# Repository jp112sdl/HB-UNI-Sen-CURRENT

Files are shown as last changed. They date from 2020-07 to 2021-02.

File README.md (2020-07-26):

# HB-UNI-Sen-CURRENT

## Universeller Stromsensor für HomeMatic
unterstützt 
 - YHDC SCT013-015; -020; -030; -050; -100 / 1V Sensoren
 - INA219 _(work in progress)_
 - ACS712 _(work in progress)_
 
 ## Beispielprojekt: 3-Phasen Strommessung im Verteilerschrank
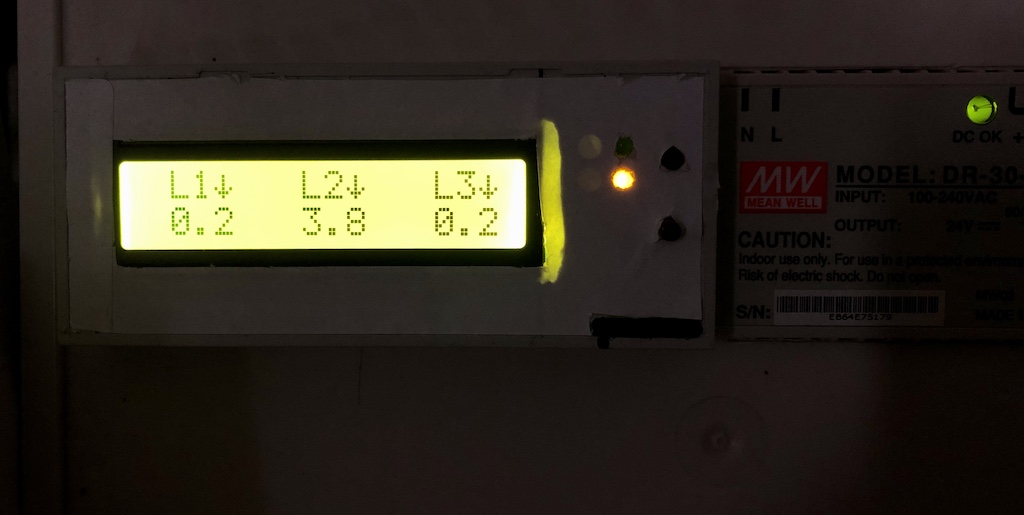
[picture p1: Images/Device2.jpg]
Dev2
 
 
 ## Bauteile
  - 1x Arduino Pro Mini (**8 MHz, 3.3V**) [AliExpress](https://de.aliexpress.com/item/32342672626.html)
  - 1x CC1101 868MHz Funkmodul [AliExpress](https://de.aliexpress.com/item/32924239954.html)
  - 2x ADS1115 16bit ADC [AliExpress](https://de.aliexpress.com/item/32954034047.html)
  - 3x SCT013-030/1V Stromsensor [AliExpress](https://de.aliexpress.com/item/4000189334448.html)
  - 1x 16x2 LCD Display [AliExpress](https://de.aliexpress.com/item/32685612494.html)
  - 2x Taster
  - 2x LED
  - 2x Widerstand 330 Ohm
  - ext. Stromversorgung 5V
 
 ## Schaltungsübersicht
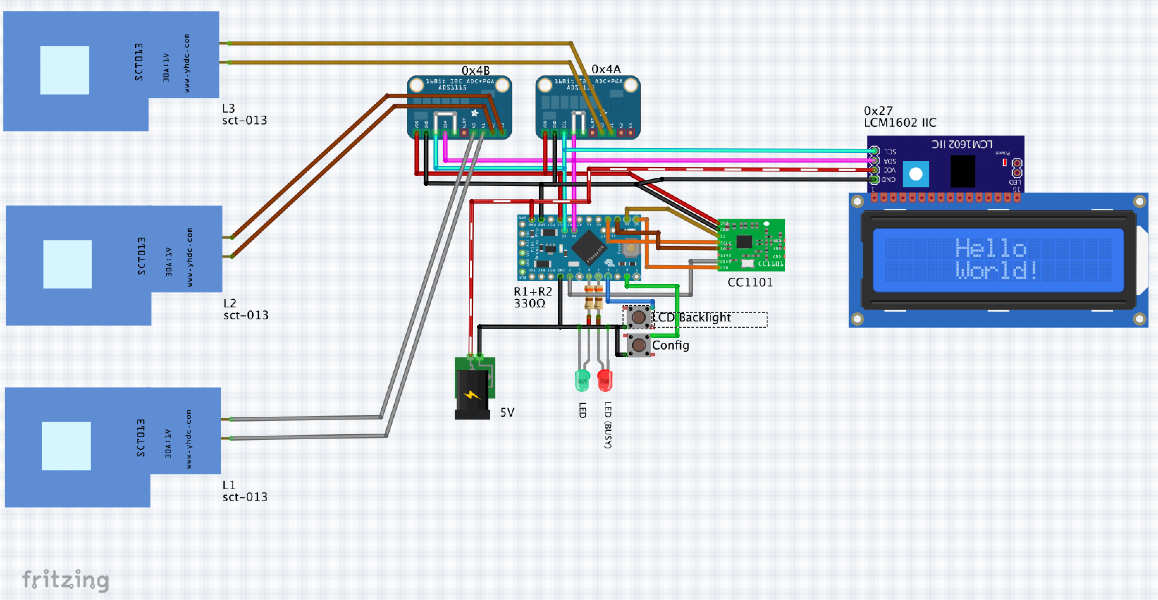
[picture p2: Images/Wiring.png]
Wiring
 
 
 ## CCU Einstellungen
 **Geräteeinstellungen**
 - Spannungsversorgung
   - Netzbetrieb
   - Batteriebetrieb (es erscheint dann zusätzlich ein Feld für die Low-Battery Einstellung)
 - Messintervall
 - Sendeintervall
   - Es wird der Mittelwert über die eingestellte Anzahl Messungen gebildet und übertragen. Der zeitliche Sendeabstand beträgt (Messintervall x Sendeintervall) Sekunden
 - Displayhinterleuchtungszeit
   - Dauer der LCD Hintergrundbeleuchtung nach Druck auf Taster 2 (0 = Dauerhaft EIN)
 - Prüfung auf Grenzwerte
   - bei jeder Messung: wird bei einer einzelnen Messung ein Grenzwert über-/unterschritten, wird sofort der Entscheidungswert gesendet
   - Mittelwert: liegt der Mittelwert (s.o.) über/unter einem Grenzwert, wird der Entscheidungswert erst im Sendeintervall gesendet
 
 **Kanaleinstellungen**
  - Sensortyp: Auswahl des verwendeten Sensortyps
  - Messdauer: Dauer der Messung (Mittelwert über n Millisekunden)
  - Oberer / Unterer Grenzwert und Entscheidungswert: hierüber lassen sich direkt verknüpfte Aktoren bei über-/unterschreiten von Grenzwerten schalten

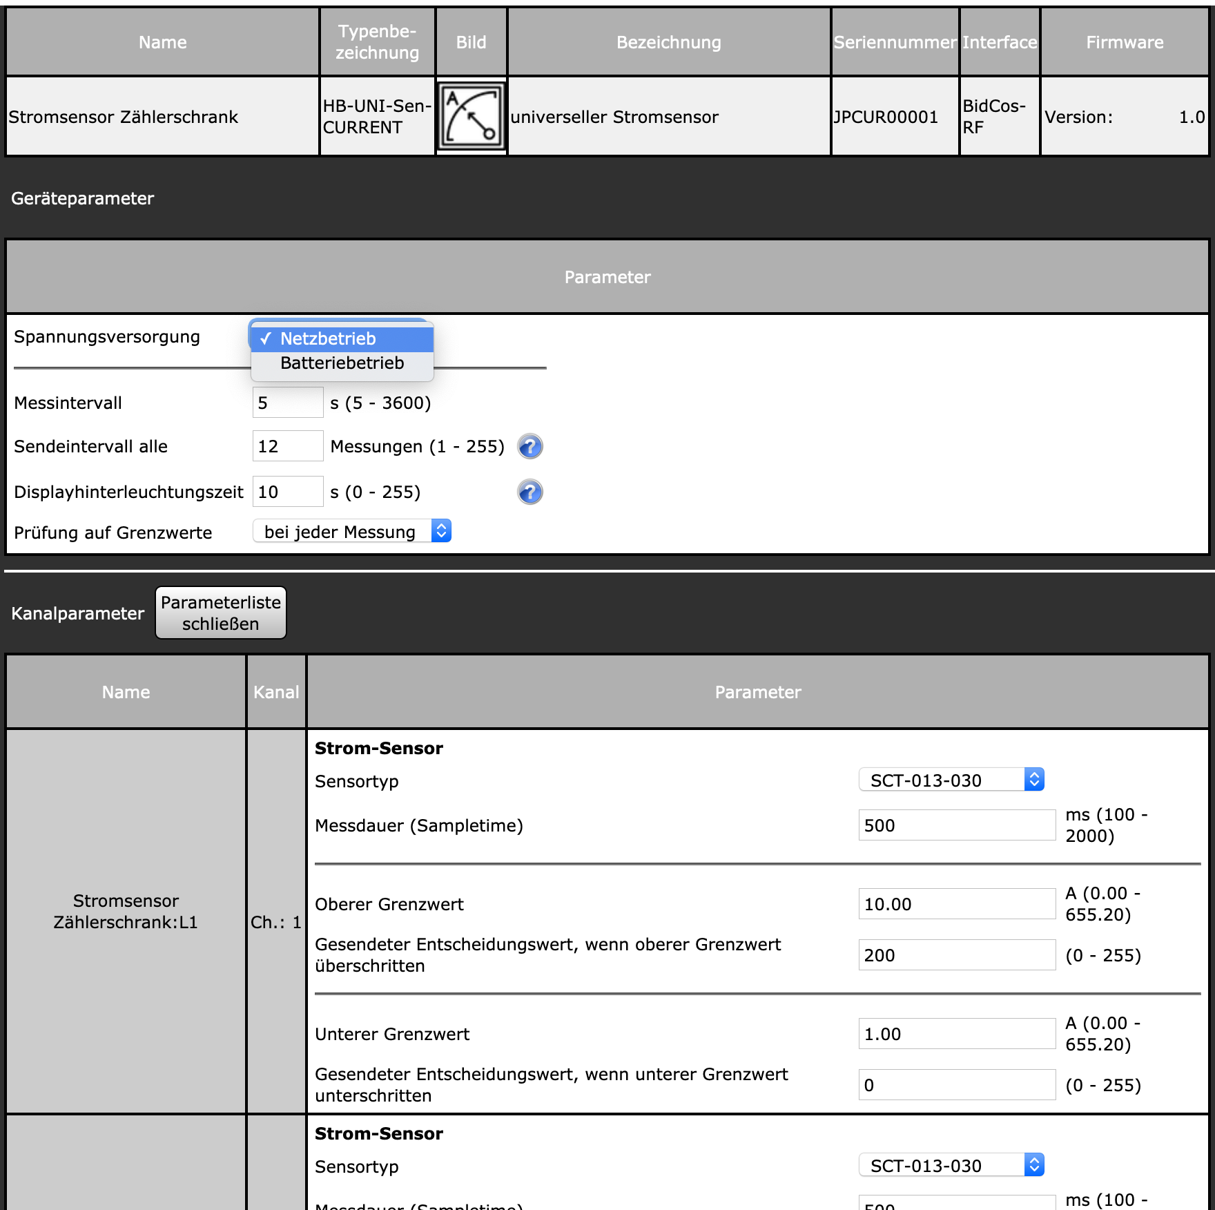
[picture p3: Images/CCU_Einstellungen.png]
Einstellungen
 

 ## CCU Bedienung
 Anzeige von aktueller Stromstärke, ggf. zuletzt gesendetem Entscheidungswert sowie Fehler (bei Ausfall eines ADS1115 Moduls)
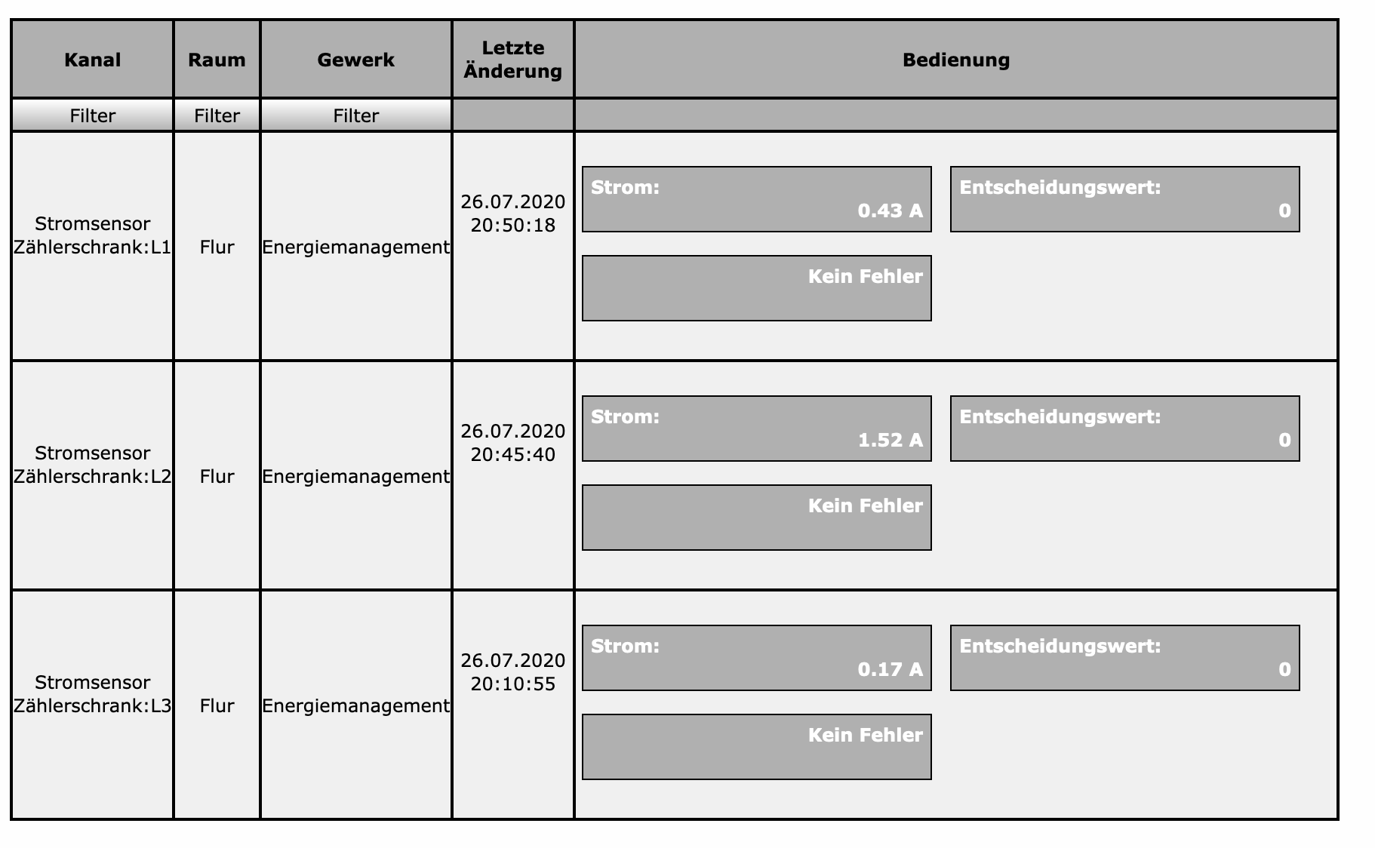
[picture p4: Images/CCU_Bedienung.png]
Bedienung


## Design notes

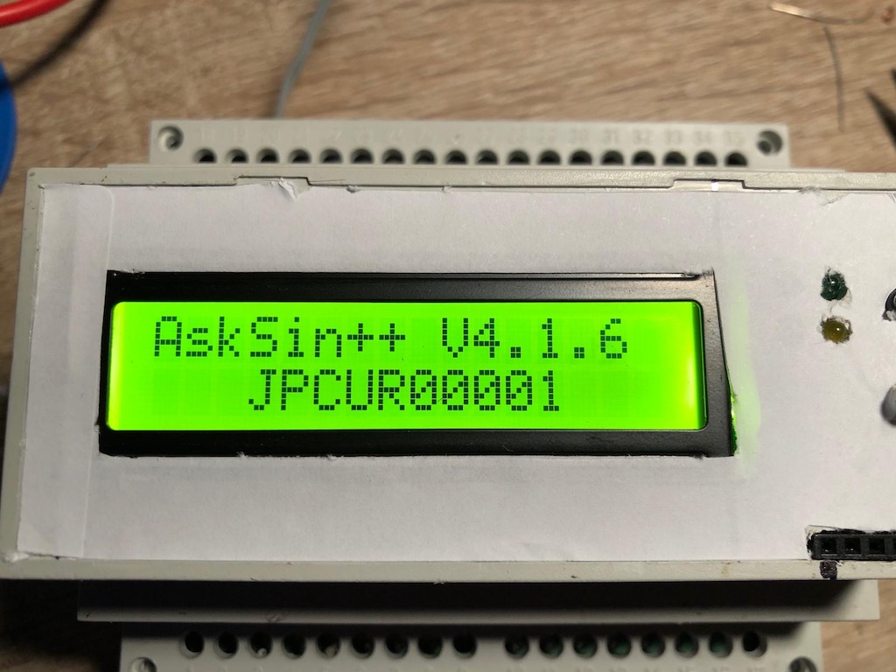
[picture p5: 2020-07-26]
Images/Device1.jpg

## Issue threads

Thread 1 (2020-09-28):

Frage zum Start

Michel83, 2020-09-28:
Hi, ich habe ein kleine Frage zum Start des Sensors.

Ist es normal das wenn ich Spannung auf den Sensor gebe die grüne LED Blinkt dann die Rote Leuchtet und im Terminal dies steht

`AskSin++ V4.1.2 (Sep 28 2020 19:35:40)
Address Space: 32 - 156
CC init1
CC Version: 14
 - ready
Config Freq: 0x2165E2
ADS1115 init at address 4B OK, gain 1024
ADS1115 init at address 4A OK, gain 1024
iVcc: 3332
`

Danach passiert erst mal eine ganze zeit nichts mehr im Display habe ich die Anzeige :

AskSinn++ V4.1.2
JPCUR00001

ich denke das ist alles so normal, das Problem was ich habe das nach einer zeit dann im Display L1 mit 0.0, L2 mit 214748, und L3 mit 0.0 steht wo muss ich suchen ?

Ich habe 50A Wandler direkt auf die ADS gelötet

Grüße
und Super Arbeit !

Michel83, 2020-09-28:
Kurzes update ich habe ihn mal angelernt, hier zeigt er auf L2 keine Werte allerdings bekomme ich die Servicemeldung mit daten stehen zur Übertragung an nicht weg
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

jp112sdl, 2020-09-28:
> allerdings bekomme ich die Servicemeldung mit daten stehen zur Übertragung an nicht weg

Configtaster mal kurz gedrückt?

> das Problem was ich habe das nach einer zeit dann im Display L1 mit 0.0, L2 mit 214748, und L3 mit 0.0 steht wo muss ich suchen ?

Hmm, bin ich auch grad überfragt. Der Wert wird ja per I2C direkt vom ADS1115 ausgelesen

Michel83, 2020-09-28:
Danke für die schnelle Antwort, was mir noch aufgefallen ist im Display fehlt bei L2 auch der Pfeil nach unten, die config Taste hatte ich kurz gedrückt wie die rote LED aus war. Danach blinkte die grüne zweimal kurz aber die Meldung in der ccu war nicht weg.

Ich versuche morgen nochmal ein anderen ProMini, da ich diesen auch seltsamer weise nur mit dem diamex Programmer beschreiben konnte also nicht mit dem ftdi

Michel83, 2020-09-29:
Hi,

ich habe nochmal getestet den ProMini habe ich noch nicht gewechselt aber mal die Adressen der ADS1115 gewechselt gleiches Phänomen L2 nur mist und kein Pfeil, danach habe ich dem ADS1115 4B die Adresse geklaut siehe :
`Address Space: 32 - 156
CC init1
CC Version: 14
 - ready
Config Freq: 0x2165E2
ADS1115 init at address 4B FAILED!
ADS1115 init at address 4A OK, gain 1024
iVcc: 3322
measure() #1 of 12
sendConditionalSwitchCommand
<- 0C 01 A2 41 F34E01 35C9DA 01 00 00  - 66891
-> 0C 50 86 70 025F31 000000 00 A7 3B  - 66895
waitAck: 00
<- 0C 01 A2 41 F34E01 35C9DA 01 00 00  - 67532
waitAck: 00
<- 0C 01 A2 41 F34E01 35C9DA 01 00 00  - 68167
waitAck: 00
<- 0C 01 A2 41 F34E01 35C9DA 01 00 00  - 68802
waitAck: 00
<- 0C 01 A2 41 F34E01 35C9DA 01 00 00  - 69439
waitAck: 00
<- 0C 01 A2 41 F34E01 35C9DA 01 00 00  - 70074
waitAck: 00
sendConditionalSwitchCommand
<- 0C 02 B2 41 F34E01 FFFFFF 03 01 FF  - 71071
waitAck: 00
<- 0C 02 B2 41 F34E01 FFFFFF 03 01 FF  - 72060
waitAck: 00
<- 0C 02 B2 41 F34E01 FFFFFF 03 01 FF  - 73050
waitAck: 00
<- 0C 02 B2 41 F34E01 FFFFFF 03 01 FF  - 74039
waitAck: 00
<- 0C 02 B2 41 F34E01 FFFFFF 03 01 FF  - 75028
waitAck: 00
<- 0C 02 B2 41 F34E01 FFFFFF 03 01 FF  - 76015
waitAck: 00
ignore 10 FF 86 53 4D0E4E 000000 00 00 8F 8E 00 02 25  - 76664
`

jetzt ist L2 auf Null allerdings fehlt nun auch bei L3 der Pfeil.

jp112sdl, 2020-09-29:
Also an den Pfeilen solltest du dich erstmal nicht orientieren.
Sie zeigen lediglich an, ob ein Grenzwert über-/unterschritten wurde.

Komisch ist auch die Zieladresse FFFFFF
```
sendConditionalSwitchCommand
<- 0C 02 B2 41 F34E01 FFFFFF 03 01 FF  - 71071
```

Du solltest noch mal einen kompletten Reset machen (Ablernen mit Werkseinstellung), um das EEPROM neu zu intialisieren.
Dann noch mal neu anlernen.

Vielleicht sind auch dann die L2 Probleme weg

Michel83, 2020-10-03:
Hi, sorry hatte heute erst Zeit zum probieren.

Er läuft, Ablernen mit Werkseinstellung war des Rätsels Lösung das L2 Problem war danach auch weg.

Jetzt habe ich zwar noch das Schönheitsproblem das bei Geräte nicht der Strom sondern der lange string steht aber damit kann ich leben.

Super Arbeit und danke nochmal für den Support.

Grüsse

jp112sdl, 2020-10-03:
> Jetzt habe ich zwar noch das Schönheitsproblem das bei Geräte nicht der Strom sondern der lange string steht

Welche CCU FW Version setzt du ein?
Bei RaspberryMatic wird das (noch?) automatisch übersetzt.
Dort gibt es in der `/www/webui/webui.js` (noch?) den Eintrag
`elvST['ENERGIE_METER_TRANSMITTER|CURRENT'] = '${stringTablePowerMeterCurrent}';`

Wie ich sehe, existiert der Eintrag in der aktuellen OCCU master aber nicht mehr. :(
Bis Version 3.51 war die Übersetzung noch drin. Grrrrr...
Immer wieder Überraschungen aufs Neue... Ich werde die Übersetzung dann in der nächsten Addon Version selbst implementieren.

jp112sdl, 2020-10-03:
Ahja, man hat `stringTablePowerMeterCurrent` in `stringTableCurrent` umbenannt.

Heißt für mich: Keinerlei vorgefertigte Übersetzungen mehr nutzen.

Closed 2020-10-03.

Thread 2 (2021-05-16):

INA219 (work in progress)

elmarfaber, 2021-05-16:
Hallo,

ich habe gerade ein Projekt wo ich die Anbindung des o.g. Sensors verwenden könnte.
Ist denn die Einbindung des INA219 noch geplant?

Viele Grüße

Elmar

jp112sdl, 2021-05-16:
Hallo Elmar,

zeitlich ist meinerseits nicht absehbar, wann und ob ich das noch einbaue.

Evtl. bekommst du es selbst hin?
Beim HB-ES-PMSw1-USB habe ich den INA219 eingebaut:
https://github.com/jp112sdl/HB-ES-PMSw1-USB/blob/master/HB-ES-PMSw1-USB.ino

elmarfaber, 2021-05-17:
Hallo Jérôme,

ich bin zwar nicht so ganz unerfahren im programmieren aber ich glaube nicht,
dass ich das hinbekomme ohne mehr über die Grundstruktur von AskSin++ zu
wissen - ist schon sehr komplex. Aber ich versuche mich mal daran...

jp112sdl, 2021-05-17:
Ich hab das mal grob in den Sketch gepackt.
https://github.com/jp112sdl/HB-UNI-Sen-CURRENT/blob/dev/ina219/HB-UNI-Sen-CURRENT.ino

Die Änderungen sind überschaubar:
https://github.com/jp112sdl/HB-UNI-Sen-CURRENT/compare/dev/ina219

NUM_CHANNELS solltest du noch auf 1 setzen
https://github.com/jp112sdl/HB-UNI-Sen-CURRENT/blob/2ed1deb66944ee0305fe46d08b8e331339dcb3b2/HB-UNI-Sen-CURRENT.ino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

elmarfaber, 2021-05-17:
Okay, das ist wirklich nicht wild, hab den Sketch nun angepasst und muss jetzt nur noch die Hardware zusammenbauen
und es testen. Habe den INA226 mal mit dazu gepackt und die xml Datei um den Parameter erweitert:
...
<paramset type="MASTER" id="HB-UNI-Sen-CURRENT_ch_master">
        <parameter id="SENSOR_TYPE">
          <logical type="option">
           <option id="SCT-013-015" />
           <option id="SCT-013-020" />
           <option id="SCT-013-030" default="true" />
           <option id="SCT-013-050" />
           <option id="SCT-013-100" />
           <option id="INA219" />
		   <option id="INA226" />
           <option id="ACS712 or other" />
          </logical>
          <physical type="integer" interface="config" list="1" index="3" size="1"/>
        </parameter>
...
Ich hoffe, ich habe alles richtig gemacht. Ich melde mich, wenn ich es getestet habe...
Vielen Dank für deine Hilfe!!!!

jp112sdl, 2021-05-17:
>die xml Datei um den Parameter erweitert

Hi,

das reicht nicht.
Die WebUI Config Page hat die Liste auch noch hier:
https://github.com/jp112sdl/JP-HB-Devices-addon/blob/master/src/addon/www/config/easymodes/HB-UNI-Sen-CURRENT_ch_master.tcl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

elmarfaber, 2021-05-21:
Hallo,

also kompilieren und aufspielen ist kein Problem, aber die Auswahlliste auf dem RasberryMatic verändert sich nicht.
ich sehe schon den Auswahlpunkt INA219 nicht... Jetzt bräuchte ich doch noch ein wenig Hilfe...

jp112sdl, 2021-05-21:
Da ist ja ein Fehler in meiner Aufzählung 😎
Hab ich noch gar nicht mitbekommen.
Es muss [hier](https://github.com/jp112sdl/JP-HB-Devices-addon/blob/master/src/addon/www/config/easymodes/HB-UNI-Sen-CURRENT_ch_master.tcl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) natürlich
```
      set options(5) "INA219"
      set options(6) "ACS712 or other"
```
heißen

elmarfaber, 2021-05-21:
Das hatte ich schon korrigiert, aber komischerweise fehlt der INA219 Eintrag und der letzte ist der "ACS712 or other"
Ich verstehe nicht warum der letzte Eintrag stimmt und der dazwischen fehlt

jp112sdl, 2021-05-21:
Wir reden hier aber von 2 verschiedenen Dingen
Das ist die XML
```
  <option id="SCT-013-100" />
  <option id="INA219" />
```
und das hier die `HB-UNI-Sen-CURRENT_ch_master.tcl`

```
  set options(5) "INA219"
  set options(6) "ACS712 or other"
```

Wenn du was an den Dateien änderst, musst du anschließend auch die ReGa und den RFD neustarten

jp112sdl, 2021-05-21:
Bei mir ist alles da
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

elmarfaber, 2021-05-21:
Ich habe die Addons 5.2 noch einmal hochgeladen Neustart und das device neu angelernt, genau das gleiche...

jp112sdl, 2021-05-21:
> Ich habe die Addons 5.2 noch einmal hochgeladen Neustart und das device neu angelernt, genau das gleiche...

Im Addon ist der Fehler doch noch drin...

> Kann das Problem im Sketch liegen?

Nein, das liegt einzig und allein an der `HB-UNI-Sen-CURRENT_ch_master.tcl`

jp112sdl, 2021-05-21:
Hier kannst du dir eine Vorab-Version der 5.3 herunterladen:
https://www.dropbox.com/s/wzzc2dvutt2d2ec/jp-hb-devices-addon-5.3-beta.tgz?dl=0

elmarfaber, 2021-05-21:
So es funktioniert! Ich habe nur einen Faktor 10 zuviel im Ergebnis, da muss ich die Initialisierung noch einmal prüfen

jp112sdl, 2021-05-21:
Gute Frage... häng die TCL mal hier an

elmarfaber, 2021-05-21:
`#!/bin/tclsh

source [file join $env(DOCUMENT_ROOT) config/easymodes/em_common.tcl]
source [file join $env(DOCUMENT_ROOT) config/easymodes/EnterFreeValue.tcl]

proc getMinValue {ps_descr param} {
  upvar ps_descr descr
  array_clear param_descr
  array set param_descr $descr($param)

  set min $param_descr(MIN)

  if {($param == "COND_TX_THRESHOLD_HI")  || ($param == "COND_TX_THRESHOLD_LO") } {
    set min [format {%.2f} $min]
  }

  return $min
}

proc getMaxValue {ps_descr param} {
  upvar ps_descr descr
  array_clear param_descr
  array set param_descr $descr($param)
  set max $param_descr(MAX)

  if {($param == "COND_TX_THRESHOLD_HI")  || ($param == "COND_TX_THRESHOLD_LO") } {
    set max [format {%.2f} $max]
  }

  return $max
}

proc getMinMaxValueDescr {ps_descr param} {
	upvar ps_descr descr
    array_clear param_descr
	array set param_descr $descr($param)
	set min $param_descr(MIN)
	set max $param_descr(MAX)

  if {($param == "COND_TX_THRESHOLD_HI")  || ($param == "COND_TX_THRESHOLD_LO") } {
    set min [format {%.2f} $min]
    set max [format {%.2f} $max]
  }

  return "($min - $max)"
}

proc getUnit {ps_descr param} {
  upvar ps_descr descr
  array_clear param_descr
  array set param_descr $descr($param)
  set unit $param_descr(UNIT)
  return "$unit"
}

proc setSelectedSensorType {selSensorType elmID} {
  puts "<script type=\"text/javasscript\">"
    puts "var options = \$\$('select#$elmID option');"
                                    
   puts "options\[$selSensorType\].selected = true;"
  puts "</script>"       
}

proc displayFields {id mode} {
  # mode can be 'show' or 'hide'
  if {$mode != "hide"} {
    set mode "show"
  }
  puts "<script type=\"text/javasscript\">"
    #puts "\$\$(\".j_custom\").invoke('$mode');"
    puts "\$\$(\"$id\").invoke('$mode');"
  puts "</script>"
}

proc set_htmlParams {iface address pps pps_descr special_input_id peer_type} {
  puts "<script type=\"text/javascript\">load_JSFunc('/config/easymodes/js/HBCurrentSensor.js');</script>"

  global iface_url

  upvar PROFILES_MAP  PROFILES_MAP
  upvar HTML_PARAMS   HTML_PARAMS
  upvar PROFILE_PNAME PROFILE_PNAME
  upvar $pps          ps
  upvar $pps_descr  ps_descr

  set url $iface_url($iface)
  set devType "HB_GENERIC"

  set comment {
    foreach val [array names ps] {
      puts "$val: $ps($val)<br/>"
    }
    foreach val [array names ps_descr] {
      puts "$val: $ps_descr($val)<br/>"
    }

    puts "<br/><br/>"
  }

  set chn [lindex [split $special_input_id _] 1]                                                                                      

  append HTML_PARAMS(separate_1) "<table class=\"ProfileTbl\">"

      append HTML_PARAMS(separate_1) "<tr><td colspan='2'>"
        append HTML_PARAMS(separate_1) "<div><b>\${stringTableConditionCurrentTitle}</b></div>"
      append HTML_PARAMS(separate_1) "</td></tr>"

    set prn 1
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
elmarfaber, 2021-05-21:
Es klappt nicht, hab jetzt sogar den Stecker gezogen, immer noch das gleiche ich werde noch verrückt...
Warum klappt die Aktuallisierung über das Addon installieren?
Ich denke ich versuche es Morgen weiter...

jp112sdl, 2021-05-21:
Nur um ein paar Basics auszuschließen:
Wie editierst du die Datei? Ist deine Änderung auch wirklich drin? Hast du das Dateisystem vorher beschreibbar gemacht?

elmarfaber, 2021-05-22:
Ich verwende WinSCP mit Admin Rechten - der Editor ist Nodepad++. Meine CCU Iist ein Raspberry mit RaspberryMatic neuste Version. Wenn ich die editierten Dateien downloade, sind die Änderungen darin enthalten.

jp112sdl, 2021-05-22:
Kommt mir alles sehr seltsam vor.
Ohne vorher das Dateisystem beschreibbar zu machen (`mount -o remount,rw /`) kann es nicht funktionieren.
Vielleicht editierst du die ganze Zeit auch die falsche Datei - die im Addonverzeichnis, denn das liegt im user-space und ist immer r/w gemountet.

elmarfaber, 2021-05-22:
Oh was ein... ja das falsche Verzeichnis war es. Jetzt klappt es
Vielen Dank für deine Hilfe!!!
Weitere Fragen, wie z.B. Erhöhen der Stellen uin der Anzeige wie 0,0025 wären hier ja fehl am Platz,
die stelle ich besser seperat im Forum?

jp112sdl, 2021-05-22:
Du meinst die Anzeige in "Status und Bedienung" -> "Geräte" ?

elmarfaber, 2021-05-22:
Genau, die Anzeige ist ja dreistellig 0.18A ich bräuchte ein oder zwei Stellen mehr
Habe auch immer noch das Problem, dass der Messwert um den Faktor 10 zu hoch ist

jp112sdl, 2021-05-22:
>  ich bräuchte ein oder zwei Stellen mehr

Das wird sehr aufwendig.

> dass der Messwert um den Faktor 10 zu hoch ist

Warum teilst du ihn nicht einfach / 10 ?
https://github.com/jp112sdl/HB-UNI-Sen-CURRENT/blob/2ed1deb66944ee0305fe46d08b8e331339dcb3b2/HB-UNI-Sen-CURRENT.ino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

`ina219.getCurrent_mA() / 10`

elmarfaber, 2021-05-22:
Geteilt hab ich ihn aber dann zeigt er mir anstatt 0.18 0.01A an oder gerundet 0.02
besser wäre eben 18mA - dann wäre meine Frage wie ich anstatt A mA anzeigen kann.
Auch verstehe ich nicht, warum der Wert um den Faktor 10 zu hoch ist, da ja die
Library mA zurück liefert

jp112sdl, 2021-05-22:
> besser wäre eben 18mA - dann wäre meine Frage wie ich anstatt A mA anzeigen kann.

mA werden z.B. beim https://github.com/jp112sdl/HB-ES-PMSw1-USB angezeigt.
Und hier die XML dazu: https://github.com/jp112sdl/JP-HB-Devices-addon/blob/master/src/addon/firmware/rftypes/hb-es-pmsw1-usb.xml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

> Auch verstehe ich nicht, warum der Wert um den Faktor 10 zu hoch ist, da ja die
Library mA zurück liefert

Vielleicht falscher current divider?

https://github.com/jp112sdl/HB-UNI-Sen-CURRENT/blob/2ed1deb66944ee0305fe46d08b8e331339dcb3b2/HB-UNI-Sen-CURRENT.ino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

Hab mich im Detail nicht weiter mit dem INA219 befasst bisher

elmarfaber, 2021-05-22:
Der gemessene Wert ist 18, was stimmt ich finde nur nicht wo daraus 0.18 werden
Ich würde eben gerne einen Wert von 18 angezeigt bekommen aber ich werde mich erst einmal
mit den Links von dir beschäftigen - ist schwirig als Einsteiger zu finden, wo was passiert :-)

elmarfaber, 2021-05-22:
So es hat alles funktioniert, ich erhalte nun einen Wert in mA. Soll ich den Sketch ablegen oder die
Änderungen irgendwo dokumentieren?
Vielen Dank für deine Ausdauer und Hilfe!!!

jp112sdl, 2021-05-22:
Hmm, das mit den mA passt nun nicht mehr wirklich zu diesem Projekt.

elmarfaber, 2021-05-22:
Ja das stimmt, aber ich wollte ein wenig mehr verstehen - letzendlich ist das HB-ES-PMSw1-USB Projekt vermutlich
mehr oder weniger genau das, was ich gesucht habe. Ich denke der INA219 passt nicht wirklich zum Projekt, er kann
ja nur 3,6A maximal und da ist die Auflösung nicht passend. Ich könnte alles rauswerfen bis auf die Initialisierung etc.
dann würde es wieder passen.

jp112sdl, 2021-05-22:
>  Ich könnte alles rauswerfen bis auf die Initialisierung etc.
dann würde es wieder passen.

Hier im Github hat sich nichts geändert. Im master-Branch ist nach wie vor der ursprüngliche Sketch enthalten.

elmarfaber, 2021-05-23:
Ich werde das am WE übertragen, ich wußte nicht genau wie weit ich komme und wollte keinen Mist eintragen
und habe erst mal alles lokal getestet.

elmarfaber, 2021-05-25:
Irgend etwas habe ich wohl falsch gemacht, habe die Änderungen eingetragen, aber jetzt sehe ich sie nicht mehr.
Wie gehe ich denn korrekter Weise vor, wenn ich Änderungen eintragen will?

jp112sdl, 2021-05-25:
Fork ziehen, Änderungen im eigenen Repository machen, Pullrequest erstellen

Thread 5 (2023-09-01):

Problem beim kompilieren

oremountains, 2023-09-01:
Hab ein Problem beim kompilieren:

habe Libary ADS1X15 isstalliert es kommt jedoch die Fehlermeldung:

**Compilation error: Sensors/Ads1x15.h: No such file or directory**

wenn ich  #include "Sensors/Ads1x15.h" ersetze durch
#include "ADS1X15.h"

dann kommt  die Fehlermeldung : **Compilation error: 'Sens_Ads1x15' does not name a type**
bezieht sich auf

`   Sens_Ads1x15<ADS1115_ADDR_1> ads1;
    Sens_Ads1x15<ADS1115_ADDR_2> ads2;`

jp112sdl, 2023-09-01:
Sieht so aus, als hättest du nicht den Ordner "Sensors" hier aus dem Projekt mit im Sketch-Verzeichnis liegen

oremountains, 2023-09-01:
(läuft auf Mac os) ja der Ordner war nicht darin hab diesen angelegt und jetz komme wieder:

          abs
/Users/g1/Documents/HB-UNI-Sen-CURRENT/HB-UNI-Sen-CURRENT.ino:31:27: error: 'adsGain_t' has not been declared
 #define ADS_SENSOR_GAIN   adsGain_t::GAIN_TWO
                           ^
/Users/g1/Documents/HB-UNI-Sen-CURRENT/HB-UNI-Sen-CURRENT.ino:369:20: note: in expansion of macro 'ADS_SENSOR_GAIN'
          ads2.init(ADS_SENSOR_GAIN);
                    ^~~~~~~~~~~~~~~

exit status 1

Compilation error: 'Sens_Ads1x15' does not name a type

jp112sdl, 2023-09-03:
Die `Adafruit_ADS1X15` Library hast du installiert?

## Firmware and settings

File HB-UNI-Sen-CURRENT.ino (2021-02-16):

//- -----------------------------------------------------------------------------------------------------------------------
// AskSin++
// 2016-10-31 papa Creative Commons - http://creativecommons.org/licenses/by-nc-sa/3.0/de/
// 2020-07-04 jp112sdl Creative Commons - http://creativecommons.org/licenses/by-nc-sa/3.0/de/
//- -----------------------------------------------------------------------------------------------------------------------
// ci-test=yes board=328p aes=no

// define this to read the device id, serial and device type from bootloader section
// #define USE_OTA_BOOTLOADER

#define LCD_ADDRESS 0x27

#define EI_NOTEXTERNAL
#include <EnableInterrupt.h>
#define SENSOR_ONLY

#include <AskSinPP.h>
#include <LowPower.h>

#include <Register.h>
#include <MultiChannelDevice.h>

#ifdef LCD_ADDRESS
#include <LiquidCrystal_I2C.h>
#define BACKLIGHT_BTN_PIN  6
#endif

#include "Sensors/Ads1x15.h"
#define ADS1115_ADDR_1 0x4B
#define ADS1115_ADDR_2 0x4A
#define ADS_SENSOR_GAIN   adsGain_t::GAIN_TWO


#define CONFIG_BUTTON_PIN  8
#define LED_PIN            4
#define BUSY_LED_PIN       5

#define NUM_CHANNELS       3

#define PEERS_PER_CHANNEL  4

using namespace as;

//Korrekturfaktor der Clock-Ungenauigkeit, wenn keine RTC verwendet wird
#define SYSCLOCK_FACTOR    0.88

enum conditionTypes { ct_none, ct_above, ct_below, ct_disabled };
typedef struct {
  uint32_t current;
  uint8_t conditionType = ct_none;
  bool ok;
} _currentSensor;

// define all device properties
const struct DeviceInfo PROGMEM devinfo = {
  {0xF3, 0x4E, 0x01},          // Device ID
  "JPCUR00001",                // Device Serial
  {0xF3, 0x4E},                // Device Model
  0x10,                        // Firmware Version
  0x53,                        // Device Type
  {0x01, 0x01}                 // Info Bytes
};

/**
   Configure the used hardware
*/
typedef AskSin<StatusLed<LED_PIN>, BatterySensor, Radio<AvrSPI<10, 11, 12, 13>, 2>> Hal;
typedef StatusLed<BUSY_LED_PIN> BusyLed;
Hal hal;

DEFREGISTER(DReg0, MASTERID_REGS, DREG_LOWBATLIMIT, 0x07, 0x1f, 0x20, 0x21, DREG_BACKONTIME, DREG_POWERSUPPLY)
class DevList0 : public RegList0<DReg0> {
  public:
    DevList0 (uint16_t addr) : RegList0<DReg0>(addr) {}

    bool Sendeintervall (uint8_t value) const {
      return this->writeRegister(0x21, value & 0xff);
    }
    uint8_t Sendeintervall () const {
      return this->readRegister(0x21, 0);
    }

    bool Messintervall (uint16_t value) const {
      return this->writeRegister(0x1f, (value >> 8) & 0xff) && this->writeRegister(0x20, value & 0xff);
    }
    uint16_t Messintervall () const {
      return (this->readRegister(0x1f, 0) << 8) + this->readRegister(0x20, 0);
    }

    bool conditionCheckAverage () const {
      return this->readRegister(0x07,0);
    }
    bool conditionCheckAverage (uint8_t value) const {
      return this->writeRegister(0x07,value);
    }

    void defaults () {
      clear();
      lowBatLimit(22);
      Sendeintervall(12);
      Messintervall(10);
      powerSupply(true); //true = battery mode
      backOnTime(10);
      conditionCheckAverage(false);
    }
};

DEFREGISTER(CReg1, CREG_AES_ACTIVE, CREG_COND_TX_THRESHOLD_HI, CREG_COND_TX_THRESHOLD_LO, CREG_COND_TX_DECISION_ABOVE, CREG_COND_TX_DECISION_BELOW, 0x01, 0x02, 0x03)
class DevList1 : public RegList1<CReg1> {
  public:
    DevList1 (uint16_t addr) : RegList1<CReg1>(addr) {}

    bool sampleTime (uint16_t value) const {
      return this->writeRegister(0x01, (value >> 8) & 0xff) && this->writeRegister(0x02, value & 0xff);
    }
    uint16_t sampleTime () const {
      return (this->readRegister(0x01, 0) << 8) + this->readRegister(0x02, 0);
    }

    bool sensorType (uint16_t value) const {
      return this->writeRegister(0x03, value & 0xff);
    }
    uint16_t sensorType () const {
      return this->readRegister(0x03, 0);
    }

    void defaults () {
      clear();
      condTxThresholdHi(1000);
      condTxDecisionAbove(200);
      condTxThresholdLo(100);
      condTxDecisionBelow(0);
      sensorType(0);
      sampleTime(500);
    }
};

class MeasureEventMsg : public Message {
  public:
    void init(uint8_t msgcnt, uint32_t *sensorValues, _currentSensor *cs, bool batlow) {
      Message::init(0xa + (NUM_CHANNELS * 3), msgcnt, 0x53, BCAST, batlow ? 0x80 : 0x00, cs[0].ok ? 0x41 : 0xC1);
      //DPRINT(F("+Current (#0) : ")); DDECLN(sensorValues[0]);
      pload[0] =  (sensorValues[0] >> 8) & 0xff;
      pload[1] = (sensorValues[0])   & 0xff;
      for (uint8_t s = 0; s < NUM_CHANNELS - 1; s++) {
        //DPRINT(F("+Current (#")); DDEC(s + 1); DPRINT(F(") : ")); DDECLN(sensorValues[s+1]);
        pload[2+(s * 3)] = (cs[s+1].ok ? 0x42 : 0xC2) + s;
        pload[3+(s * 3)] = (sensorValues[s+1] >> 8) & 0xff;
        pload[4+(s * 3)] =  sensorValues[s+1]       & 0xff;
      }
    }
};

#ifdef LCD_ADDRESS
class LcdType :  public Button {
public:
  class BacklightAlarm : public Alarm {
    LcdType& lcdDev;
  public:
    BacklightAlarm (LcdType& l) :  Alarm(0), lcdDev(l) {}
    virtual ~BacklightAlarm () {}
    void restartTimer(uint8_t sec) {
      sysclock.cancel(*this);
      set(seconds2ticks(sec));
      lcdDev.lcd.backlight();
      sysclock.add(*this);
    }

    virtual void trigger (__attribute__((unused)) AlarmClock& clock) {
      lcdDev.lcd.noBacklight();
    }
  }backlightalarm;
private:
  bool _present;
  bool first;
  uint8_t backlightOnTime;

  byte arrowUp[8] = { 0b00000, 0b00100, 0b01110, 0b10101, 0b00100, 0b00100, 0b00100, 0b00000 };
  byte arrowDown[8] = { 0b00000, 0b00100, 0b00100, 0b00100, 0b10101, 0b01110, 0b00100, 0b00000 };

public:
  LiquidCrystal_I2C lcd;
  LcdType () :  backlightalarm(*this), _present(false), first(true), backlightOnTime(10), lcd(LCD_ADDRESS, 16, 2){}
  virtual ~LcdType () {}

  void displayValues(_currentSensor *cs) {
    if (_present == true) {
      if (first) {
        first = false;
       lcd.setCursor(0, 0);
       lcd.print(" L1    L2    L3 ");
      }
     lcd.setCursor(0, 1);
     lcd.print("                ");

     lcd.setCursor(cs[0].current > 999 ? 0 : 1, 1);
     lcd.print(cs[0].current / 100.0, 1);

     lcd.setCursor(cs[1].current > 999 ? 6 : 7, 1);
     lcd.print(cs[1].current / 100.0, 1);

     lcd.setCursor(cs[2].current > 999 ? 12 : 13, 1);
     lcd.print(cs[2].current / 100.0, 1);
    }
  }

  void showCondition(uint8_t conditionType, uint8_t channel) {
    lcd.setCursor(channel * 6 + 3, 0);
    if (conditionType == ct_above) lcd.write(byte(0));
    if (conditionType == ct_below) lcd.write(byte(1));
    if (conditionType == ct_none) lcd.print("*");
    if (conditionType == ct_disabled) lcd.print(" ");
  }

  void initLCD(uint8_t *serial) {
    Wire.begin();
    Wire.beginTransmission(LCD_ADDRESS);
    if (Wire.endTransmission() == 0) {
      _present = true;
      lcd.init();
      lcd.createChar(0, arrowUp);
      // create a new character
      lcd.createChar(1, arrowDown);
      lcd.backlight();
      lcd.setCursor(0, 0);
      lcd.print(ASKSIN_PLUS_PLUS_IDENTIFIER);
      lcd.setCursor(3, 1);
      lcd.setContrast(200);
      lcd.print((char*)serial);

      if (backlightOnTime > 0) backlightalarm.restartTimer(backlightOnTime);

    } else {
      DPRINT("LCD Display not found at 0x");DHEXLN((uint8_t)LCD_ADDRESS);
    }
  }

  void setBackLightOnTime(uint8_t t) {
    backlightOnTime = t;
    if (backlightOnTime == 0)
      lcd.backlight();
    else
      lcd.noBacklight();
  }

  virtual void state(uint8_t s) {
    Button::state(s);
    if (s==released ) {
      if (backlightOnTime > 0) backlightalarm.restartTimer(backlightOnTime);
    }
  }
};
LcdType lcd;
#endif

class MeasureChannel : public Channel<Hal, DevList1, EmptyList, List4, PEERS_PER_CHANNEL, DevList0> {
  private:
    enum sensorTypes { SCT013015, SCT013020, SCT013030, SCT013050, SCT0130100, INA219, ACS712_or_other };
  public:
    MeasureChannel () : Channel() {}
    virtual ~MeasureChannel () {}

    virtual void configChanged() {
    /*  DPRINT("configChanged on Ch");DDECLN(number());
      DPRINT("condTxThresholdHi  : ");DDECLN(this->getList1().condTxThresholdHi());
      DPRINT("condTxDecisionAbove: ");DDECLN(this->getList1().condTxDecisionAbove());
      DPRINT("condTxThresholdLo  : ");DDECLN(this->getList1().condTxThresholdLo());
      DPRINT("condTxDecisionBelow: ");DDECLN(this->getList1().condTxDecisionBelow());
      DPRINT("sensorType         : ");DDECLN(this->getList1().sensorType());
      DPRINT("sampleTime         : ");DDECLN(this->getList1().sampleTime());*/
    }

    void checkConditions(_currentSensor *sensor) {
      uint8_t sIdx = number()-1;

      static uint8_t evcnt  = 0;
      uint8_t decisionValue = 0;
      bool sendConditionalSwitchCommand = false;

      uint32_t current     = sensor[sIdx].current;
      uint16_t thresholdHi = this->getList1().condTxThresholdHi();
      uint16_t thresholdLo = this->getList1().condTxThresholdLo();

      if (thresholdHi > 0) {
        SensorEventMsg& rmsg = (SensorEventMsg&)device().message();

        if (current > thresholdHi && sensor[sIdx].conditionType != ct_above) {
          sensor[sIdx].conditionType = ct_above;
          decisionValue = this->getList1().condTxDecisionAbove();
          sendConditionalSwitchCommand = true;
        }

        if (current < thresholdLo && sensor[sIdx].conditionType != ct_below) {
          sensor[sIdx].conditionType = ct_below;
          decisionValue = this->getList1().condTxDecisionBelow();
          sendConditionalSwitchCommand = true;
        }

        if (sendConditionalSwitchCommand == true) {
          DPRINTLN("sendConditionalSwitchCommand");
          rmsg.init(device().nextcount(), number(), evcnt++, decisionValue, false , false);
          device().sendPeerEvent(rmsg, *this);
        }
        lcd.showCondition(sensor[sIdx].conditionType, sIdx);
      } else {
        lcd.showCondition(ct_disabled, sIdx);
      }

    }

    uint8_t sctFactor() {
      uint8_t sensorType = this->getList1().sensorType();
      switch (sensorType) {
        case SCT013015:
          return 15;
        case SCT013020:
          return 20;
        case SCT013030:
          return 30;
        case SCT013050:
          return 50;
        case SCT0130100:
          return 100;
        default:
          return 0;
      }
    }

    uint16_t sampleTime() {
      return this->getList1().sampleTime();
    }

    uint8_t status () const { return 0; }
    uint8_t flags  () const { return device().battery().low() ? 0x80 : 00; }
};

class DevType : public MultiChannelDevice<Hal, MeasureChannel, NUM_CHANNELS, DevList0> {
private:
  bool powerModeBattery;
  uint16_t txInterval;
  uint16_t measureInterval;
  bool boot;
  bool lcd_present;
  BusyLed busyLed;
public:
  class CurrentSensors : public Alarm {
    DevType&   dev;
    Sens_Ads1x15<ADS1115_ADDR_1> ads1;
    Sens_Ads1x15<ADS1115_ADDR_2> ads2;
    _currentSensor cs[NUM_CHANNELS];
    uint32_t cumulatedCurrentValues[NUM_CHANNELS];
    uint8_t measureCount;
    public:
       CurrentSensors (DevType& d) : Alarm(0), dev(d), measureCount(0) {}
       virtual ~CurrentSensors () {}
       void measure() {
         //measurement here:
         cs[0].current = ads1.getCurrent_0_1(dev.channel(1).sampleTime(), dev.channel(1).sctFactor());cs[0].ok = ads1.checkSensor();
         cs[1].current = ads1.getCurrent_2_3(dev.channel(2).sampleTime(), dev.channel(2).sctFactor());cs[1].ok = ads1.checkSensor();
         cs[2].current = ads2.getCurrent_0_1(dev.channel(3).sampleTime(), dev.channel(3).sctFactor());cs[2].ok = ads2.checkSensor();

#ifdef LCD_ADDRESS
         lcd.displayValues(cs);
#endif
       }

       void init() {
         ads1.init(ADS_SENSOR_GAIN);
         ads2.init(ADS_SENSOR_GAIN);
       }

       virtual void trigger (__attribute__ ((unused)) AlarmClock& clock) {
         dev.busyLed.ledOn();
         measure();
         dev.busyLed.ledOff();

         // add measured current to the cumulated values
         cumulatedCurrentValues[0] += cs[0].current;
         cumulatedCurrentValues[1] += cs[1].current;
         cumulatedCurrentValues[2] += cs[2].current;

         measureCount++;
         DPRINT("measure() #");DDEC(measureCount);DPRINT(" of ");DDECLN(dev.txInterval);

         // check if any of the sensors is above/below a threshold
         for (uint8_t ch = 0; ch < NUM_CHANNELS; ch++) {
           // check conditions on each measure() or only on txInterval
           if (dev.getList0().conditionCheckAverage() == false) {
             dev.channel(ch+1).checkConditions(cs);
           } else {
             if (measureCount >= dev.txInterval) {
               cs[ch].current = cumulatedCurrentValues[ch] / measureCount;
               dev.channel(ch+1).checkConditions(cs);
             }
           }
         }

         set(seconds2ticks(max(10, dev.measureInterval * SYSCLOCK_FACTOR)));

         // send the cyclic message 
         if (measureCount >= dev.txInterval) {
           bool batlow = dev.onBattery() ? dev.battery().low() : false;

           // divide cumulated values by measure count
           for (uint8_t ch = 0; ch < NUM_CHANNELS; ch++)
             cumulatedCurrentValues[ch] /= measureCount;
             
           MeasureEventMsg& msg = (MeasureEventMsg&)dev.message();             
           msg.init(dev.nextcount(), cumulatedCurrentValues, cs, batlow);
           dev.broadcastEvent(msg);

           // reset values
           measureCount = 0;
           for (uint8_t s = 0; s < NUM_CHANNELS; s++)
             cumulatedCurrentValues[s] = 0;
         }
         sysclock.add(*this);
       }
    } currentSensors;

  typedef MultiChannelDevice<Hal, MeasureChannel, NUM_CHANNELS, DevList0> TSDevice;
  DevType(const DeviceInfo& info, uint16_t addr) : TSDevice(info, addr), powerModeBattery(true), txInterval(0), measureInterval(0), boot(true), lcd_present(false), currentSensors(*this) {}
  virtual ~DevType () {}

  void init (Hal& hal) {
    TSDevice::init(hal);
    currentSensors.init();
    busyLed.init();
    busyLed.ledOn(seconds2ticks(2));
  }

  virtual void configChanged () {
    TSDevice::configChanged();
    uint8_t batlow = max(this->getList0().lowBatLimit(),19);
    // DPRINT(F("*LOWBAT Limit: "));DDECLN(batlow);
    this->battery().low(batlow);

    if (this->getList0().Messintervall() != measureInterval) {
      measureInterval = this->getList0().Messintervall();
      //DPRINT(F("*ME Intervall: ")); DDECLN(measureInterval);
      if (boot == false) {
        sysclock.cancel(currentSensors);
        currentSensors.set(seconds2ticks(max(10, measureInterval) * SYSCLOCK_FACTOR));
      } else {
        currentSensors.set(seconds2ticks(3));
      }
      sysclock.add(currentSensors);
    }

    txInterval = max(1, this->getList0().Sendeintervall());
    //DPRINT(F("*TX Intervall: ")); DDECLN(txInterval);

    onBattery(this->getList0().powerSupply());
    //DPRINT(F("*Batterymode : ")); DDECLN(onBattery());

    uint8_t bOn = this->getList0().backOnTime();
    //DPRINT(F("*LCD Backlight Ontime : ")); DDECLN(bOn);
    lcd.setBackLightOnTime(bOn);

    //bool cc = this->getList0().conditionCheckAverage();
    //DPRINT(F("*Condition Check on Average : ")); DDECLN(cc);

    boot = false;
  }

  void onBattery(bool bat) {
    powerModeBattery = bat;
  }

  bool onBattery() {
    return powerModeBattery;
  }
};

DevType sdev(devinfo, 0x20);
ConfigButton<DevType> cfgBtn(sdev);


void setup () {
  DINIT(57600, ASKSIN_PLUS_PLUS_IDENTIFIER);
  sdev.init(hal);
  buttonISR(cfgBtn, CONFIG_BUTTON_PIN);
  hal.battery.init(seconds2ticks(60UL * 60), sysclock);
  hal.battery.critical(19);
  sdev.initDone();
#ifdef LCD_ADDRESS
  uint8_t serial[11];
  sdev.getDeviceSerial(serial);
  serial[10]=0;
  lcd.initLCD(serial);
  buttonISR(lcd, BACKLIGHT_BTN_PIN);
#endif
}

void loop() {
  bool worked = hal.runready();
  bool poll = sdev.pollRadio();
  if ( worked == false && poll == false ) {
    if (sdev.onBattery() == true)
      hal.activity.savePower<Sleep<>>(hal);
    else
      hal.activity.savePower<Idle<>>(hal);
  }
}

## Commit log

2020-07-18 check if sensor is present
2020-07-21 add sensor check
2020-07-26 add fritzing file
    [wiring.fzz]
